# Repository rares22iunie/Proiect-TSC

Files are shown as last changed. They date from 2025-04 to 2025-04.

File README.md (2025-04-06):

# OpenBook eBook Reader
Acest proiect reprezintă un cititor de eBook-uri portabil, cu consum redus de energie, afișaj E-Ink și conectivitate modernă, proiectat în jurul microcontrollerului ESP32-C6-WROOM-1-N8.

# Arhitectură hardware
- Microcontroller – ESP32-C6-WROOM-1-N8
- Procesor RISC-V

- Conectivitate: Wi-Fi 6 și Bluetooth 5

- Suport criptografie hardware

- Flash extern NOR de 64MB (W25Q512JVEIQ), conectat pe magistrală SPI dedicată

Interfețe: SPI, I2C, GPIO

## Sistem de alimentare
- Conector USB-C (PMF0501) – intrare standard 5V

- Protecție ESD pentru liniile USB (USBLC6-2SC6Y)

- Circuit de încărcare Li-Po (MCP73831), max. 500 mA

- Baterie Li-Po 3.7V

- Regulator LDO 3.3V (MCP1700-3302E) pentru alimentarea circuitelor

## Afișaj E-Ink
- Conector compatibil cu ecrane E-Paper de 1.54” (200x200 px)

- Circuit dedicat de generare a tensiunii (tranzistor, inductor, diodă)

- Jumper selector pentru tipul de ecran (SJ1)

- Interfață SPI + pini GPIO pentru control, conectat la ESP32-C6

## Memorie externă
- Card SD (SPI) pentru stocarea fișierelor eBook

- Memorie NOR Flash de 64MB (W25Q512JVEIQ) pentru resurse firmware (fonturi, imagini)

## Senzori și periferice
- BME688 – senzor de temperatură, umiditate, presiune, compuși volatili (I2C)

- DS3231SN – modul RTC de precizie (I2C)

- MAX17048G-T10 – monitorizare baterie (fuel gauge, I2C)

- Butoane pentru reset și boot (GPIO)

- Conector Qwiic / Stemma QT pentru extensii rapide I2C
# Block Diagram


# Design PCB și carcasă
- Placă PCB organizată în blocuri funcționale: alimentare, MCU, afișaj, senzori

- Trasee optimizate și plan de masă comun

- Protecții ESD incluse

- Conectori externi ușor accesibili (USB, butoane, display)

- Randări 3D disponibile

- Carcasă 3D compactă și ergonomică, gata de printare/turnare

# Conexiuni ESP32-C6
| Componenta | Interfata  | Pini ESP32-C6 | Observatii |
|---|---|---|---|
| SD Card | SPI | GPIO10, GPIO11, GPIO12, GPIO13 | Bus SPI pentru card SD |
| NOR Flash | SPI | GPIO6, GPIO7, GPIO8, GPIO9 | Bus SPI separat |
| E-Ink Display  | SPI + GPIO | GPIO18, GPIO19, GPIO20, GPIO21 | Control display si date |
| BME688 | I2C | GPIO1 (SDA), GPIO2 (SCL) | Bus comun I2C |
| DS3231 | I2C | GPIO1 (SDA), GPIO2 (SCL) | Comun cu ceilalti senzori |
| MAX17048 | I2C | GPIO1 (SDA), GPIO2 (SCL) | Comun cu ceilalti senzori |
| Butoane | GPIO | GPIO0 (RST), GPIO3 (BOOT) | Control de sistem |
| Test Pads | GPIO/UART  | GPIO17, GPIO22 | Debug |
| Stemma/Qwiic | I2C | GPIO1 (SDA), GPIO2 (SCL) | Extensii rapide |

# Estimare consum de energie
| Modul | Consum mediu |
|---|---|
| ESP32-C6 activ | ~80-100 mA |
| ESP32-C6 deep sleep | ~10 uA |
| E-Ink refresh | ~25 mA (temporar) |
| SD Card (idle/acces) | ~2 mA / ~50 mA |
| RTC + BME688 standby | ~3-5 uA |
| MAX17048 | ~3 uA |

**Durata estimata cu baterie 500mAh:**

- Utilizare activă: 15–20 ore

- Standby (deep sleep): până la câteva săptămâni

# Bill of Materials

| Cantitate | Componentă | Valoare | Descriere | Carcasă | Reper | Link Cumpărare | Datasheet |
|---|---|---|---|---|---|---|---|
| 1 | ADAFRUIT_LEDCHIP-LED0603 | - | LED | ADAFRUIT_CHIP-LED0603 | CHG_LED | [link](https://www.mouser.com/ProductDetail/Adafruit/CHIP-LED0603) | [datasheet](https://www.mouser.com/datasheet/2/737/CHIP-LED0603-1877199.pdf) |
| 1 | SJ | - | SMD solder JUMPER | SJ | SJ1 | [link](https://www.mouser.com/ProductDetail/TE-Connectivity/1-2176091-2) | [datasheet](https://www.mouser.com/datasheet/2/418/1-2176091-2-1817091.pdf) |
| 1 | ESP32_WROVER_EAGLE-LTSPICE_RR0402  | 0.47Ω | Rezistor | ESP32_WROVER_EAGLE-LTSPICE_R0402| R3 | [link](https://www.mouser.com/ProductDetail/Vishay/CRCW04020047ZRT7) | [datasheet](https://www.mouser.com/datasheet/2/427/crcwce-1764191.pdf) |
| 1 | ESP32_WROVER_EAGLE-LTSPICE_RR0402  | 100KΩ | Rezistor | ESP32_WROVER_EAGLE-LTSPICE_R0402| R1_PWRUSB | [link](https://www.mouser.com/ProductDetail/Vishay/CRCW0402100KFKED) | [datasheet](https://www.mouser.com/datasheet/2/427/crcwce-1764191.pdf) |
| 8 | EAGLE-LTSPICE_CC0402 | 100nF | Condensator | EAGLE-LTSPICE_C0402 | C1, C2, C4_USB, C6, C8, C9, C10, C_DELAY | [link](https://www.mouser.com/ProductDetail/Murata/GRM155R71C104KA88D) | [datasheet](https://www.mouser.com/datasheet/2/281/GRM155R71C104KA88D-1767201.pdf) |
| 1 | RCL_CPOL-EUCT3528 | 100µF | Condensator polarizat | RCL_CT3528 | C3 | [link](https://www.mouser.com/ProductDetail/Panasonic/EEE-FK1V101P) | [datasheet](https://www.mouser.com/datasheet/2/315/EEE-FK1V101P-1526881.pdf) |
| 10 | ESP32_WROVER_EAGLE-LTSPICE_RR0402  | 10KΩ | Rezistor | ESP32_WROVER_EAGLE-LTSPICE_R0402| R1, R1-PINH, R1_PINH1, R2-PINH, R2_PINH1, R4, R_BOOT, R_CHANGE, R_CL1, R_RESET | [link](https://www.mouser.com/ProductDetail/Vishay/CRCW040210K0FKED) | [datasheet](https://www.mouser.com/datasheet/2/427/crcwce-1764191.pdf) |
| 6 | ESP32_WROVER_EAGLE-LTSPICE_RR0402  | 10kΩ | Rezistor | ESP32_WROVER_EAGLE-LTSPICE_R0402| R5, R6, R7, R8, R9, R10 | [link](https://www.mouser.com/ProductDetail/Vishay/CRCW040210K0FKED) | [datasheet](https://www.mouser.com/datasheet/2/427/crcwce-1764191.pdf) |
| 1 | EAGLE-LTSPICE_CC0402 | 10µF | Condensator | EAGLE-LTSPICE_C0402 | C7 | [link](https://www.mouser.com/ProductDetail/Murata/GRM155R61A106ME44D) | [datasheet](https://www.mouser.com/datasheet/2/281/GRM155R61A106ME44D-1767201.pdf) |
| 1 | 112A-TAAR-R03_ATTEND | - | Micro SD Card Socket, Push-Push Type | 112ATAARR03ATTEND | J4 | [link](https://www.mouser.com/ProductDetail/Attend/112A-TAAR-R03) | [datasheet](https://www.mouser.com/datasheet/2/828/112A-TAAR-R03-1222862.pdf) |
| 1 | ESP32_WROVER_EAGLE-LTSPICE_RR0402  | 15Ω | Rezistor | ESP32_WROVER_EAGLE-LTSPICE_R0402| R_CAPACITOR  | [link](https://www.mouser.com/ProductDetail/Vishay/CRCW040215R0FKED) | [datasheet](https://www.mouser.com/datasheet/2/427/crcwce-1764191.pdf) |
| 1 | EAGLE-LTSPICE_CC0402 | 1µF | Condensator | EAGLE-LTSPICE_C0402 | C5 | [link](https://www.mouser.com/ProductDetail/Murata/GRM155R61A105KE15D) | [datasheet](https://www.mouser.com/datasheet/2/281/GRM155R61A105KE15D-1767201.pdf) |
| 10 | EAGLE-LTSPICE_CC0402 | 1µF/50V | Condensator ceramic multi-strat | 0402 | EPD_C1, EPD_C2, EPD_C5, EPD_C6, EPD_C7, EPD_C8, EPD_C9, EPD_C10, EPD_C11, EPD_C12 | [link](https://www.mouser.com/ProductDetail/Murata-Electronics/GRM155R61A105KE15D) | [datasheet](https://www.mouser.com/datasheet/2/281/1/GRM155R61A105KE15_01A-1983730.pdf) |

# Aplicații posibile
- eBook Reader offline

- Afișaj de birou cu date locale (calendar, vreme, informații personale)

- Platformă portabilă pentru aplicații IoT low-power

# Resurse
- Documentație oficială ESP32-C6: https://www.espressif.com/en/products/modules/esp32-c6

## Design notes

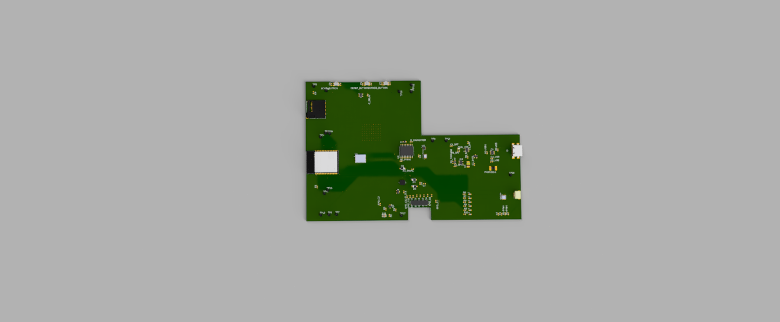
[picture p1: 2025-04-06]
Images/Board render.png

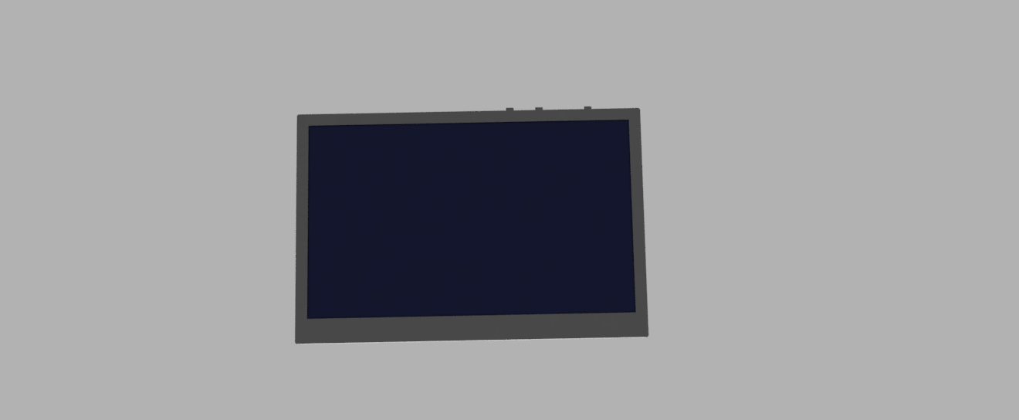
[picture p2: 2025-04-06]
Images/Device front render.PNG

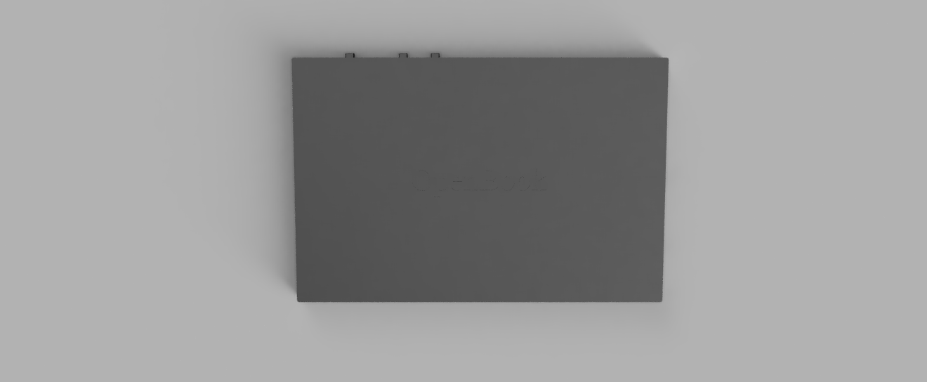
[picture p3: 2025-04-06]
Images/Device rear render.PNG

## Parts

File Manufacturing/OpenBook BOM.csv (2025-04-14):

Qty | Value | Device | Package | Parts | Description | ARROW_PART_NUMBER | ARROW_PRICE-STOCK | AVAILABILITY | CENTROID_NOT_SPECIFIED | CHECK_PRICES | COPYRIGHT | DATASHEET | DESCRIPTION | DIGIKEY_DESCRIPTION | DIGIKEY_PART_NUMBER | HEIGHT | LEAD_FREE | MANUFACTURER_NAME | MANUFACTURER_PART_NUMBER | MF | MFR_NAME | MOUSER_PART_NUMBER | MOUSER_PRICE-STOCK | MOUSER_TESTING_PART_NUMBER | MOUSER_TESTING_PRICE-STOCK | MP | MPN | PACKAGE | POPULARITY | PREFIX | PRICE | PROD_ID | PURCHASE-URL | ROHS | SNAPEDA_LINK | SPICEMODEL | SPICEPREFIX | TEMPERATURE_RANGE_HIGH | TEMPERATURE_RANGE_LOW | TP_SIGNAL_NAME | VALUE
1 |  | ADAFRUIT_LEDCHIP-LED0603 | ADAFRUIT_CHIP-LED0603 | CHG_LED | LED
1 |  | SJ | SJ | SJ1 | SMD solder JUMPER |  |  |  |  |  |  |  |  |  |  |  |  |  |  |  |  |  |  |  |  |  |  |  | 3
1 | 0.1uF/50V | EAGLE-LTSPICE_CC0402 | EAGLE-LTSPICE_C0402 | EPD_C5 | CAPACITOR, European symbol |  |  |  |  |  |  |  |  |  |  |  |  |  |  |  |  |  |  |  |  |  |  |  |  |  |  |  |  |  |  | NONE | C
1 | 0.47 | ESP32_WROVER_EAGLE-LTSPICE_RR0402 | ESP32_WROVER_EAGLE-LTSPICE_R0402 | R3 | RESISTOR, European symbol |  |  |  |  |  |  |  |  |  |  |  |  |  |  |  |  |  |  |  |  |  |  |  |  |  |  |  |  |  |  | NONE | R
1 | 100K | ESP32_WROVER_EAGLE-LTSPICE_RR0402 | ESP32_WROVER_EAGLE-LTSPICE_R0402 | R1_PWRUSB | RESISTOR, European symbol |  |  |  |  |  |  |  |  |  |  |  |  |  |  |  |  |  |  |  |  |  |  |  |  |  |  |  |  |  |  | NONE | R
8 | 100nF | EAGLE-LTSPICE_CC0402 | EAGLE-LTSPICE_C0402 | C1, C2, C4_USB, C6, C8, C9, C10, C_DELAY | CAPACITOR, European symbol |  |  |  |  |  |  |  |  |  |  |  |  |  |  |  |  |  |  |  |  |  |  |  |  |  |  |  |  |  |  | NONE | C
1 | 100uF TANT | RCL_CPOL-EUCT3528 | RCL_CT3528 | C3 | POLARIZED CAPACITOR, European symbol |  |  |  |  |  |  |  |  |  |  |  |  |  |  |  |  |  |  |  |  |  |  |  | 0 |  |  |  |  |  |  |  | C
10 | 10K | ESP32_WROVER_EAGLE-LTSPICE_RR0402 | ESP32_WROVER_EAGLE-LTSPICE_R0402 | R1, R1-PINH, R1_PINH1, R2-PINH, R2_PINH1, R4, R_BOOT, R_CHANGE, R_CL1, R_RESET | RESISTOR, European symbol |  |  |  |  |  |  |  |  |  |  |  |  |  |  |  |  |  |  |  |  |  |  |  |  |  |  |  |  |  |  | NONE | R
6 | 10k | ESP32_WROVER_EAGLE-LTSPICE_RR0402 | ESP32_WROVER_EAGLE-LTSPICE_R0402 | R5, R6, R7, R8, R9, R10 | RESISTOR, European symbol |  |  |  |  |  |  |  |  |  |  |  |  |  |  |  |  |  |  |  |  |  |  |  |  |  |  |  |  |  |  | NONE | R
1 | 10uF | EAGLE-LTSPICE_CC0402 | EAGLE-LTSPICE_C0402 | C7 | CAPACITOR, European symbol |  |  |  |  |  |  |  |  |  |  |  |  |  |  |  |  |  |  |  |  |  |  |  |  |  |  |  |  |  |  | NONE | C
1 | 112A-TAAR-R03_ATTEND | 112A-TAAR-R03_ATTEND | 112ATAARR03ATTEND | J4 | Micro SD Card Socket, Push-Push Type, Top Mount, SMT, H=1.83mm, 10u |  |  |  |  |  |  |  | Micro SD Card Socket | Push-Push Type | Top Mount | SMT | H=1.83mm | 10u |  |  | 1.9mm |  | ATTEND | 112A-TAAR-R03 ATTEND
1 | 15 | ESP32_WROVER_EAGLE-LTSPICE_RR0402 | ESP32_WROVER_EAGLE-LTSPICE_R0402 | R_CAPACITOR | RESISTOR, European symbol |  |  |  |  |  |  |  |  |  |  |  |  |  |  |  |  |  |  |  |  |  |  |  |  |  |  |  |  |  |  | NONE | R
1 | 1uF | EAGLE-LTSPICE_CC0402 | EAGLE-LTSPICE_C0402 | C5 | CAPACITOR, European symbol |  |  |  |  |  |  |  |  |  |  |  |  |  |  |  |  |  |  |  |  |  |  |  |  |  |  |  |  |  |  | NONE | C
9 | 1uF/50V | EAGLE-LTSPICE_CC0402 | EAGLE-LTSPICE_C0402 | EPD_C1, EPD_C2, EPD_C6, EPD_C7, EPD_C8, EPD_C9, EPD_C10, EPD_C11, EPD_C12 | CAPACITOR, European symbol |  |  |  |  |  |  |  |  |  |  |  |  |  |  |  |  |  |  |  |  |  |  |  |  |  |  |  |  |  |  | NONE | C
1 | 2.2 | ESP32_WROVER_EAGLE-LTSPICE_RR0402 | ESP32_WROVER_EAGLE-LTSPICE_R0402 | R2 | RESISTOR, European symbol |  |  |  |  |  |  |  |  |  |  |  |  |  |  |  |  |  |  |  |  |  |  |  |  |  |  |  |  |  |  | NONE | R
1 | 200 | ESP32_WROVER_EAGLE-LTSPICE_RR0402 | ESP32_WROVER_EAGLE-LTSPICE_R0402 | R1_BAT | RESISTOR, European symbol |  |  |  |  |  |  |  |  |  |  |  |  |  |  |  |  |  |  |  |  |  |  |  |  |  |  |  |  |  |  | NONE | R
2 | 20V/4.2A/52mO/1.4W | ESP32_WROVER_SPARKFUN-DISCRETESEMI_MOSFET_PCH-DMG2305UX-7 | ESP32_WROVER_SPARKFUN-DISCRETESEMI_SOT23-3 | Q1, Q2 | P-channel MOSFETs |  |  |  |  |  |  |  |  |  |  |  |  |  |  |  |  |  |  |  |  |  |  |  |  |  |  | TRAN-14388 |  |  |  |  |  |  |  |  | 20V/4.2A/52mO/1.4W
1 | 2K | ESP32_WROVER_EAGLE-LTSPICE_RR0402 | ESP32_WROVER_EAGLE-LTSPICE_R0402 | R2_BAT | RESISTOR, European symbol |  |  |  |  |  |  |  |  |  |  |  |  |  |  |  |  |  |  |  |  |  |  |  |  |  |  |  |  |  |  | NONE | R
4 | 4.7uF | EAGLE-LTSPICE_CC0402 | EAGLE-LTSPICE_C0402 | C1_BAT, C1_BAT2, C2_BAT, C5_USB | CAPACITOR, European symbol |  |  |  |  |  |  |  |  |  |  |  |  |  |  |  |  |  |  |  |  |  |  |  |  |  |  |  |  |  |  | NONE | C
1 | 4.7uF | ESP32_WROVER_EAGLE-LTSPICE_CC0402 | ESP32_WROVER_EAGLE-LTSPICE_C0402 | C1_BAT1 | CAPACITOR, European symbol |  |  |  |  |  |  |  |  |  |  |  |  |  |  |  |  |  |  |  |  |  |  |  |  |  |  |  |  |  |  | NONE | C
1 | 4.7uF/25V | EAGLE-LTSPICE_CC0402 | EAGLE-LTSPICE_C0402 | C4 | CAPACITOR, European symbol |  |  |  |  |  |  |  |  |  |  |  |  |  |  |  |  |  |  |  |  |  |  |  |  |  |  |  |  |  |  | NONE | C
1 | 5K1 | ESP32_WROVER_EAGLE-LTSPICE_RR0402 | ESP32_WROVER_EAGLE-LTSPICE_R0402 | R2-USB1 | RESISTOR, European symbol |  |  |  |  |  |  |  |  |  |  |  |  |  |  |  |  |  |  |  |  |  |  |  |  |  |  |  |  |  |  | NONE | R
1 | 5k1 | ESP32_WROVER_EAGLE-LTSPICE_RR0402 | ESP32_WROVER_EAGLE-LTSPICE_R0402 | R2-USB | RESISTOR, European symbol |  |  |  |  |  |  |  |  |  |  |  |  |  |  |  |  |  |  |  |  |  |  |  |  |  |  |  |  |  |  | NONE | R
1 | 68uH | 744043680IND_4828-WE-TPC_WRE | IND_4828-WE-TPC_WRE | L1 |  |  |  |  |  |  | Copyright (C) 2024 Ultra Librarian. All rights reserved. |  |  |  |  |  |  |  | 744043680 |  | Wurth Electronics
1 | BD5229G-TR | BD5229G-TR | SOT95P280X125-5N | IC1 | Voltage Detector with Adjustable Delay Time: CMOS processes are utilized to develop high precision, low current consumption CMOS reset ICs that allow arbitrary setting of the delay time. The extensive lineup includes both Nch Open Drain and CMOS output types in a wide range of detection voltages (from 2.3V to 6.0V, in 0.1V steps), enabling selection of the ideal solution based on customer requirements. In addition, the entire series is of course both lead-free and RoHS-compliant. |  |  |  |  |  |  |  | Voltage Detector with Adjustable Delay Time: CMOS processes are utilized to develop high precision | low current consumption CMOS reset ICs that allow arbitrary setting of the delay time. The extensive lineup includes both Nch Open Drain and CMOS output types in a wide range of detection voltages (from 2.3V to 6.0V | in 0.1V steps) | enabling selection of the ideal solution based on customer requirements. In addition | the entire series is of course both lead-free and RoHS-compliant. |  |  | 1.25mm |  | ROHM Semiconductor | BD5229G-TR |  |  | 755-BD5229G-TR | https://www.mouser.co.uk/ProductDetail/ROHM-Semiconductor/BD5229G-TR?qs=4kLU8WoGk0vvnhrrYwdszw%3D%3D
1 | BME688 | ESP32_WROVER_BME680_BME680 | ESP32_WROVER_BME680_PSON80P300X300X100-8N | SENSOR2 | Integrated Environmental Unit |  |  | Unavailable |  |  |  |  | Integrated Environmental Unit |  |  |  |  |  |  | Bosch Sensortec |  |  |  |  |  | BME680 |  | LGA-8 Bosch Tools |  |  | None
3 | BUTTON_CUSYOMV1 | BUTTON_CUSYOMV1 | MYBUTTON | BOOT_BUTTON, CHANGE_BUTTON, RESET_BUTTON
1 | CPH3225A | CPH3225A | CAPCP3225X100N | C10_SUPERCAP | Cap 0.011F 3.3V 1210 Flat Check availability |  |  | Not in stock |  | https://www.snapeda.com/parts/CPH3225A/Seiko+Instruments/view-part/?ref=eda |  |  | 11 mF (EDLC) Supercapacitor 3.3 V 1210 (3225 Metric) - - |  |  |  |  |  |  | Seiko Instruments |  |  |  |  |  | CPH3225A |  | 1210 Seiko |  |  | None |  | https://www.snapeda.com/api/url_track_click_mouser/?unipart_id=562593&manufacturer=Seiko Instruments&part_name=CPH3225A&search_term=None |  | https://www.snapeda.com/parts/CPH3225A/Seiko+Instruments/view-part/?ref=snap
1 | DS3231SN# | DS3231SN# | SOIC127P1032X265-16N | U3 | Real Time Clock Serial 16-Pin SOIC W T/R Check availability |  |  | In Stock |  | https://www.snapeda.com/parts/DS3231SN%23/Analog+Devices/view-part/?ref=eda |  |  | Extremely Accurate I²C-Integrated RTC/TCXO/Crystal |  |  |  |  |  |  | Analog Devices |  |  |  |  |  | DS3231SN# |  | SOIC-16 Maxim |  |  | None |  | https://www.snapeda.com/api/url_track_click_mouser/?unipart_id=99048&manufacturer=Analog Devices&part_name=DS3231SN#&search_term=None |  | https://www.snapeda.com/parts/DS3231SN%23/Analog+Devices/view-part/?ref=snap
1 | ESP32-C6-WROOM-1-N8 | ESP32-C6-WROOM-1-N8 | XCVR_ESP32-C6-WROOM-1-N8 | U2 | Check availability |  |  | In Stock |  | https://www.snapeda.com/parts/ESP32-C6-WROOM-1-N8/Espressif+Systems/view-part/?ref=eda |  |  | Multiprotocol Modules ESP32-C6 module | Wi-Fi 6 in 2.4 GHz band | Bluetooth 5 | Zigbee 3.0 and Thread. ESP34-WROOM Compatible - ENGINEERING SAMPLE |  |  |  |  |  |  | Espressif Systems |  |  |  |  |  | ESP32-C6-WROOM-1-N8 |  | None |  |  | None |  |  |  | https://www.snapeda.com/parts/ESP32-C6-WROOM-1-N8/Espressif+Systems/view-part/?ref=snap
1 | ESP32C6_VARISTORCN1812 | ESP32C6_VARISTORCN1812 | ESP32C6_VARISTOR_CT/CN1812 | PFMF.050.1 | VARISTOR |  |  |  |  |  |  |  |  |  |  |  |  |  |  |  |  |  |  |  |  |  |  |  | 0
2 | ESP32_WROVER_AVX---SD0805S020S1R0_AVX_SD0805S020S1R0_0_0AVX_SD0805S020S1R0_0_0 | ESP32_WROVER_AVX---SD0805S020S1R0_AVX_SD0805S020S1R0_0_0AVX_SD0805S020S1R0_0_0 | ESP32_WROVER_AVX---SD0805S020S1R0_AVX_SD0805S020S1R0_0 | D2, D7 | Schottky Barrier Rectifier Diode |  |  |  | No |  |  | http://datasheets.avx.com/schottky.pdf |  | DIODE SCHOTTKY 20V 1A 0805 | 478-7800-1-ND |  | yes |  |  | AVX |  | 581-SD0805S020S1R0 |  |  |  |  |  | 0805 (2012 metric) |  | D |  |  |  | yes |  |  |  | +125°C | -55°C
1 | ESP32_WROVER_SPARKFUN-IC-POWER_MCP73831 | ESP32_WROVER_SPARKFUN-IC-POWER_MCP73831 | ESP32_WROVER_SPARKFUN-IC-POWER_SOT23-5 | U5 | MCP73831T Li-Ion, Li-Pol Controller |  |  |  |  |  |  |  |  |  |  |  |  |  |  |  |  |  |  |  |  |  |  |  |  |  |  | IC-09995
1 | FH34SRJ-24S-0.5SH_99_ | FH34SRJ-24S-0.5SH_99_ | FH34SRJ24S05SH99 | J1 | (0.50mm) Surface Mount, Right Angle |  |  |  |  |  |  |  | 24 Position FFC | FPC Connector Contacts | (0.50mm) Surface Mount | Right Angle |  |  | 1.1mm |  | Hirose | FH34SRJ-24S-0.5SH(99) |  |  | 798-FH34SRJ24S05SH99 | https://www.mouser.co.uk/ProductDetail/Hirose-Connector/FH34SRJ-24S-0.5SH99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
1 | MAX17048G+T10 | MAX17048G+T10 | SON50P200X200X80-9N | U4 | Check availability |  |  | In Stock |  | https://www.snapeda.com/parts/MAX17048G+T10/Analog+Devices/view-part/?ref=eda |  |  | 3µA 1-Cell/2-Cell Fuel Gauge with ModelGauge |  |  |  |  |  |  | Analog Devices |  |  |  |  |  | MAX17048G+T10 |  | TDFN-8 Maxim |  |  | None |  | https://www.snapeda.com/api/url_track_click_mouser/?unipart_id=329239&manufacturer=Analog Devices&part_name=MAX17048G+T10&search_term=None |  | https://www.snapeda.com/parts/MAX17048G+T10/Analog+Devices/view-part/?ref=snap
3 | MBR0530 | MBR0530 | SOD3716X135N | D3, D4, D5 | ON SEMICONDUCTOR - MBR0530 - DIODE, SCHOTTKY, 0.5A, 30V, SOD-123 |  |  | In Stock |  | https://www.snapeda.com/parts/MBR0530/Onsemi/view-part/?ref=eda |  |  | Diode Schottky 30 V 500mA Surface Mount SOD-123 |  |  |  |  |  |  | ON Semiconductor |  |  |  |  |  | MBR0530 |  | SOD-123-2 ON Semiconductor |  |  | None |  | https://www.snapeda.com/api/url_track_click_mouser/?unipart_id=179458&manufacturer=ON Semiconductor&part_name=MBR0530&search_term=None |  | https://www.snapeda.com/parts/MBR0530/Onsemi/view-part/?ref=snap
6 | PGB1010603MR | PGB1010603MR | DIOC1608X36N | D6, D8, D9, D10, D11, D12 | Check availability |  |  | In Stock |  | https://www.snapeda.com/parts/PGB1010603MR/Littelfuse/view-part/?ref=eda |  |  | 150V (Typ) Clamp - Ipp Tvs Diode Surface Mount 0603 (1608 Metric) |  |  |  |  |  |  | Littelfuse Inc. |  |  |  |  |  | PGB1010603MR |  | 0603 Littelfuse Inc. |  |  | None |  | https://www.snapeda.com/api/url_track_click_mouser/?unipart_id=5659453&manufacturer=Littelfuse Inc.&part_name=PGB1010603MR&search_term=None |  | https://www.snapeda.com/parts/PGB1010603MR/Littelfuse/view-part/?ref=snap
1 | QWIIC_RIGHT_ANGLE | QWIIC_CONNECTORJS-1MM | JST04_1MM_RA | J3 | SparkFun I2C Standard Qwiic Connector |  |  |  |  |  |  |  |  |  |  |  |  |  |  |  |  |  |  |  |  |  |  |  |  |  |  | CONN-13694 |  |  |  |  |  |  |  |  | QWIIC_RIGHT_ANGLE
1 | SAMACSYS_PARTS_USB4110-GF-A | SAMACSYS_PARTS_USB4110-GF-A | SAMACSYS_PARTS_USB4110GFA | J2 | CONN USB 2.0 TYPE-C R/A SMT |  |  |  |  |  |  |  | CONN USB 2.0 TYPE-C R/A SMT |  |  | 3.26mm |  | GCT (GLOBAL CONNECTOR TECHNOLOGY) | USB4110-GF-A |  |  | 640-USB4110-GF-A | https://www.mouser.co.uk/ProductDetail/GCT/USB4110-GF-A?qs=KUoIvG%2F9IlYiZvIXQjyJeA%3D%3D
1 | SI1308EDL-T1-GE3 | SI1308EDL-T1-GE3 | SOT65P210X110-3N | Q3 | MOSFET N-Ch 30V 1.5A TrenchFET SC70 Vishay Si1308EDL-T1-GE3 N-channel MOSFET Transistor, 1.5 A, 30 V, 3-Pin SC-70 |  |  | In Stock |  | https://www.snapeda.com/parts/SI1308EDL-T1-GE3/Vishay+Siliconix/view-part/?ref=eda |  |  | Si1308EDL-T1-GE3 N-channel MOSFET Transistor | 1.5 A | 30 V | 3-Pin SC-70 | Siliconix / Vishay SI1308EDL-T1-GE3 |  |  |  |  |  |  | Vishay Siliconix |  |  |  |  |  | SI1308EDL-T1-GE3 |  | SOT-323 Vishay Semiconductor |  |  | None |  | https://www.snapeda.com/api/url_track_click_mouser/?unipart_id=274603&manufacturer=Vishay Siliconix&part_name=SI1308EDL-T1-GE3&search_term=None |  | https://www.snapeda.com/parts/SI1308EDL-T1-GE3/Vishay+Siliconix/view-part/?ref=snap
17 | TPTP20R | TPTP20R | TP20R | TP1, TP2, TP3, TP4, TP5, TP6, TP7, TP8, TP9, TP10, TP11, TP12, TP13, TP14, TP15, TP16, TP17 | Test pad |  |  |  |  |  |  |  |  |  |  |  |  |  |  |  |  |  |  |  |  |  |  |  | 2
1 | USBLC6-2SC6Y | USBLC6-2SC6Y | SOT95P280X145-6N | D1 | Low Cap. ESD Protection Auto SOT-23-6 STMicroelectronics USBLC6-2SC6Y, Dual Uni-Directional TVS Diode Array, 6-Pin SOT-23 |  |  | In Stock |  | https://www.snapeda.com/parts/USBLC6-2SC6Y/STMicroelectronics/view-part/?ref=eda |  |  | 17V Clamp 5A (8/20µs) Ipp Tvs Diode Surface Mount SOT-23-6 |  |  |  |  |  |  | STMicroelectronics |  |  |  |  |  | USBLC6-2SC6Y |  | SOT-23-6 STMicroelectronics |  |  | None |  |  |  | https://www.snapeda.com/parts/USBLC6-2SC6Y/STMicroelectronics/view-part/?ref=snap
1 | W25Q512JVEIQ | W25Q512JVEIQ | SON127P600X800X80-9N | U1 | Check availability |  |  | In Stock |  | https://www.snapeda.com/parts/W25Q512JVEIQ/Winbond+Electronics/view-part/?ref=eda |  |  | FLASH - NOR Memory IC 512Mb (64M x 8) SPI - Quad I/O 133 MHz 8-WSON (8x6) |  |  |  |  |  |  | Winbond Electronics |  |  |  |  |  | W25Q512JVEIQ |  | Package |  |  | None |  |  |  | https://www.snapeda.com/parts/W25Q512JVEIQ/Winbond+Electronics/view-part/?ref=snap
1 | XC6220A331MR-G | XC6220A331MR-G | SOT95P280X120-5N | IC4 | LDO Voltage Regulators |  |  |  |  |  |  |  | LDO Voltage Regulators |  |  | 1.2mm |  | Torex | XC6220A331MR-G |  |  | 865-XC6220A331MR-G | https://www.mouser.co.uk/ProductDetail/Torex-Semiconductor/XC6220A331MR-G?qs=AsjdqWjXhJ8ZSWznL1J0gg%3D%3D

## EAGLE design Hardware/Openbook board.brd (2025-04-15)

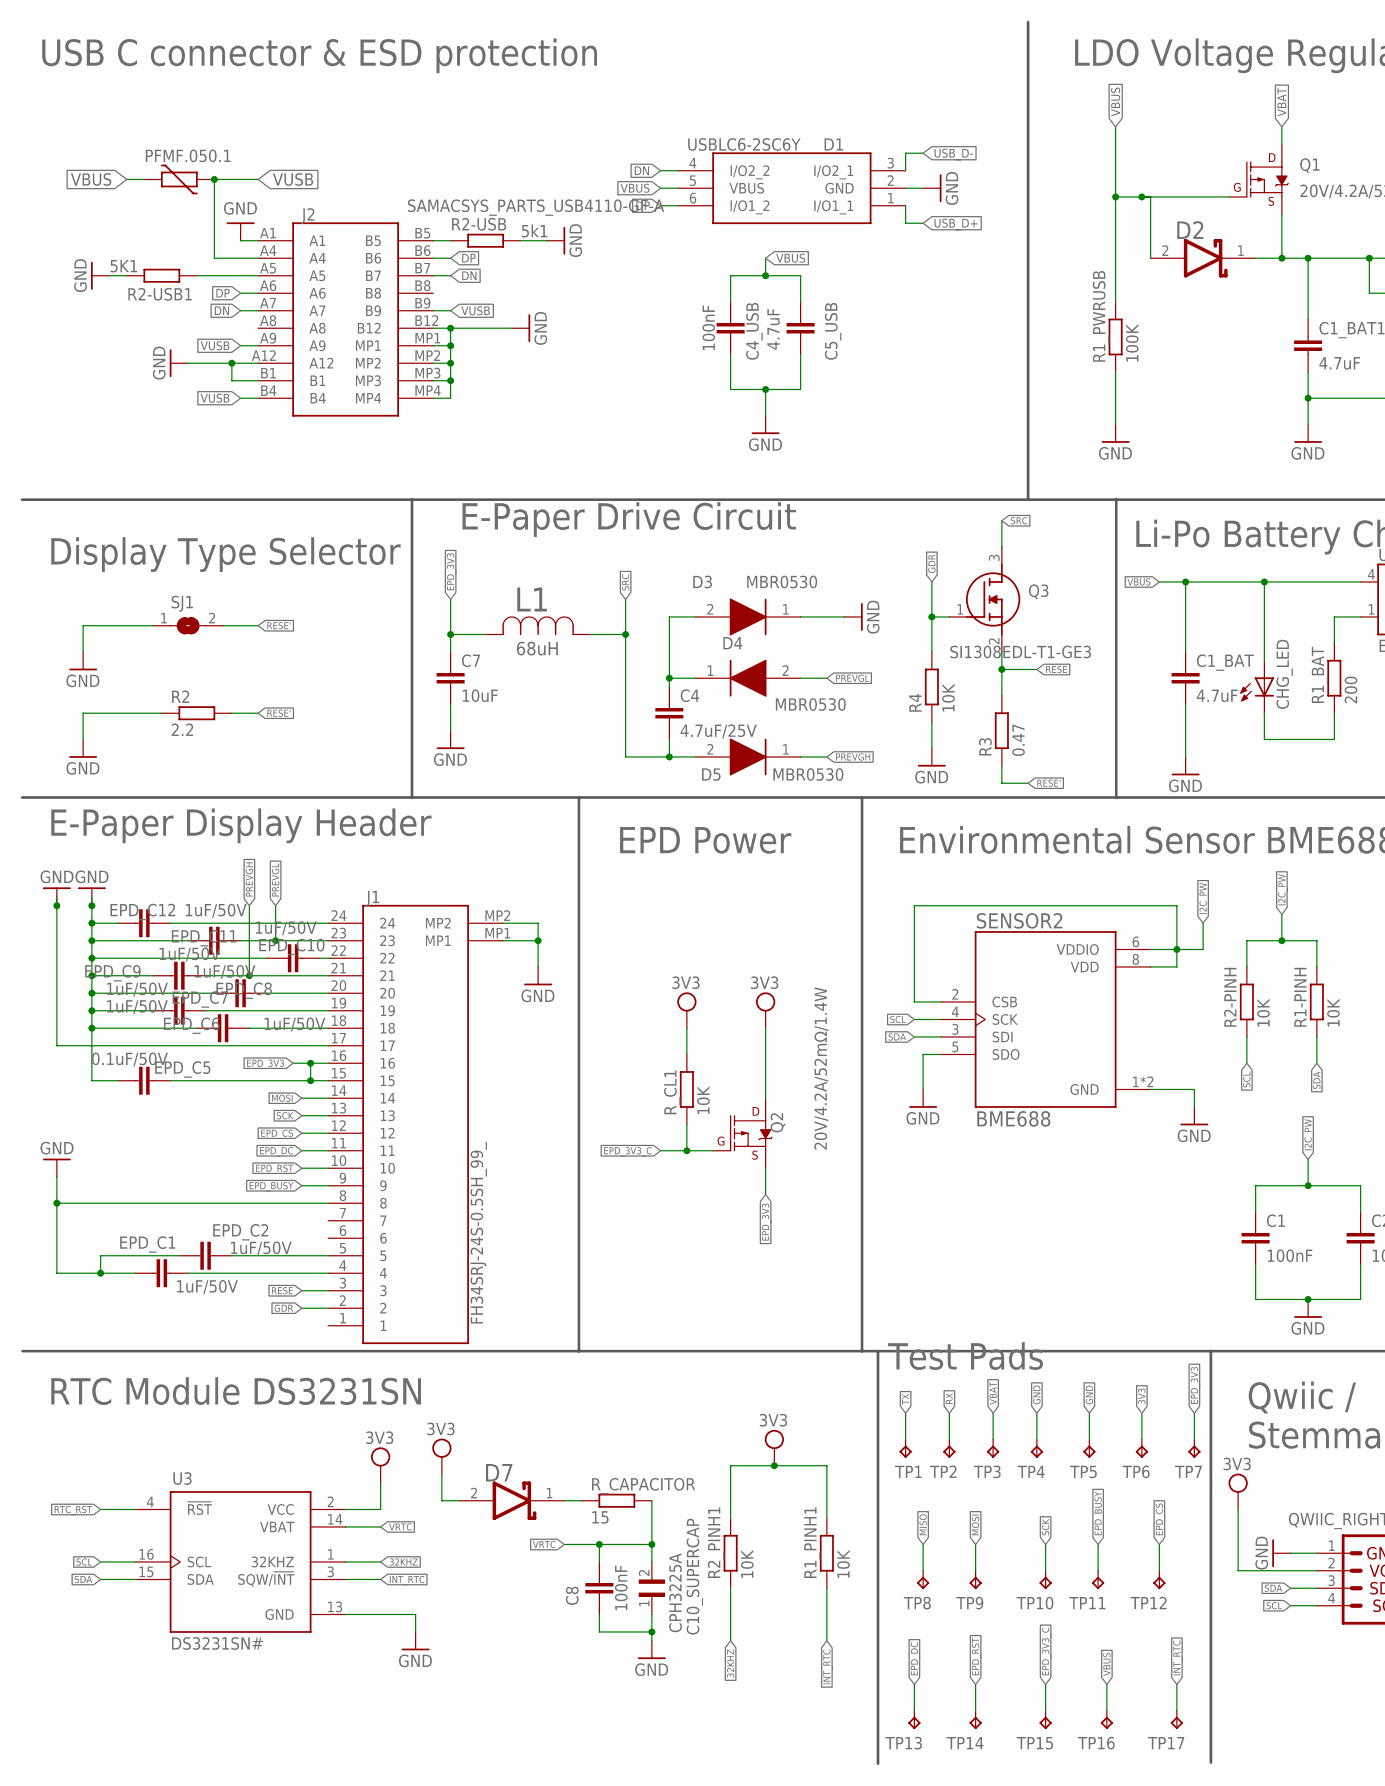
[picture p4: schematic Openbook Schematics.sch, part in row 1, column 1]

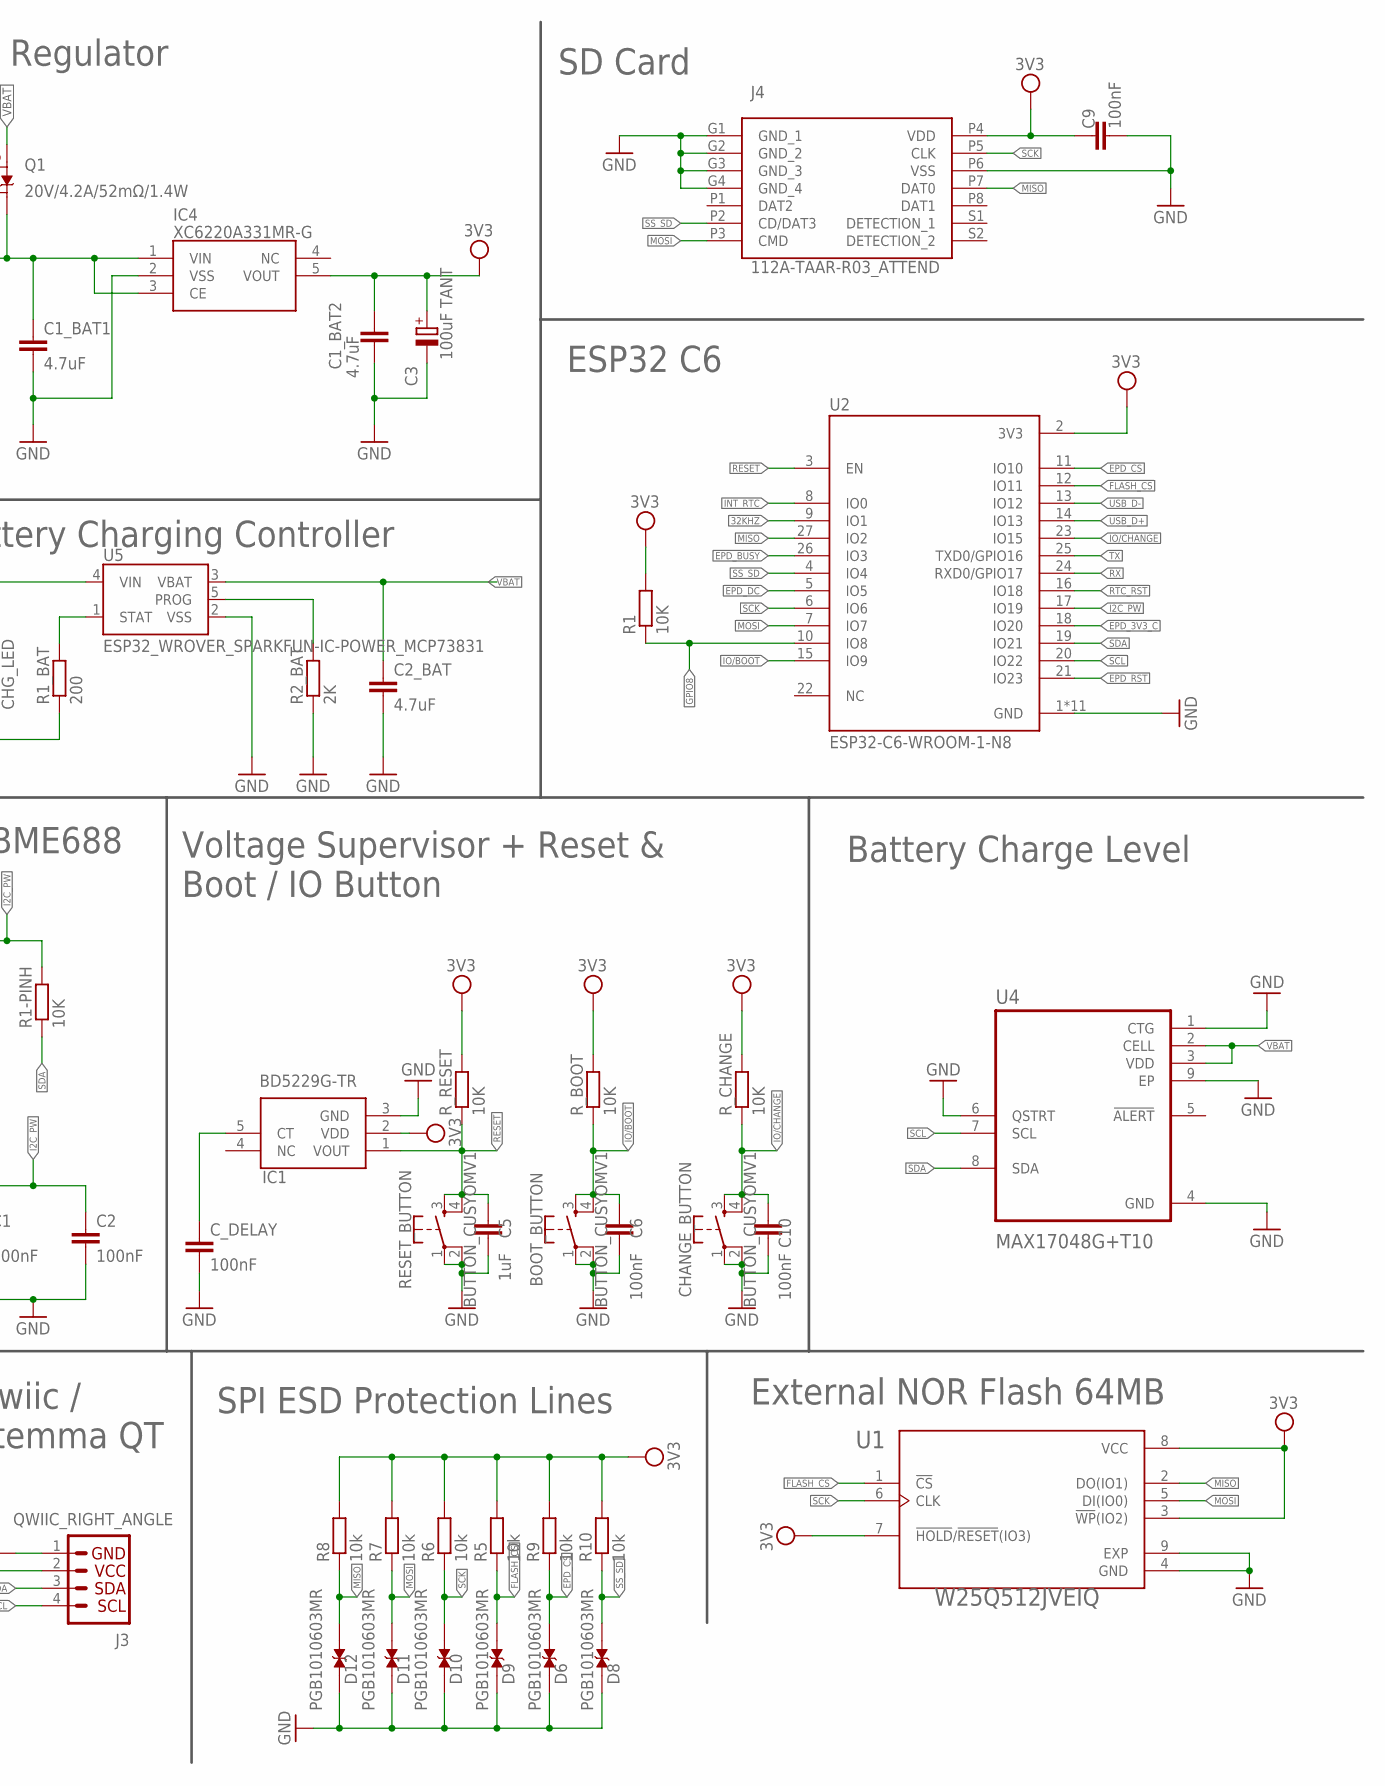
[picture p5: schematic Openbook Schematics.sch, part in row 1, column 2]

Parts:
BOOT_BUTTON: BUTTON_CUSYOMV1; MYBUTTON
C1, C2, C4_USB, C6, C8, C9, C10: 100nF; EAGLE-LTSPICE_C0402
C1_BAT, C1_BAT2, C2_BAT, C5_USB: 4.7uF; EAGLE-LTSPICE_C0402
C1_BAT1: 4.7uF; ESP32_WROVER_EAGLE-LTSPICE_C0402
C3: 100uF TANT; RCL_CT3528
C4: 4.7uF/25V; EAGLE-LTSPICE_C0402
C5: 1uF; EAGLE-LTSPICE_C0402
C7: 10uF; EAGLE-LTSPICE_C0402
C10_SUPERCAP: CPH3225A; CAPCP3225X100N
CHANGE_BUTTON: BUTTON_CUSYOMV1; MYBUTTON
CHG_LED: ADAFRUIT_LEDCHIP-LED0603; ADAFRUIT_CHIP-LED0603
C_DELAY: 100nF; EAGLE-LTSPICE_C0402
D1: USBLC6-2SC6Y; SOT95P280X145-6N
D2, D7: ESP32_WROVER_AVX---SD0805S020S1R0_AVX_SD0805S020S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; ESP32_WROVER_AVX---SD0805S020S1R0_AVX_SD0805S020S1R0_0
D3, D4, D5: MBR0530; SOD3716X135N
D6, D8, D9, D10, D11, D12: PGB1010603MR; DIOC1608X36N
EPD_C1, EPD_C2, EPD_C6, EPD_C7, EPD_C8, EPD_C9, EPD_C10, EPD_C11, EPD_C12: 1uF/50V; EAGLE-LTSPICE_C0402
EPD_C5: 0.1uF/50V; EAGLE-LTSPICE_C0402
IC1: BD5229G-TR; SOT95P280X125-5N
IC4: XC6220A331MR-G; SOT95P280X120-5N
J1: FH34SRJ-24S-0.5SH_99_; FH34SRJ24S05SH99
J2: SAMACSYS_PARTS_USB4110-GF-A; SAMACSYS_PARTS_USB4110GFA
J3: QWIIC_RIGHT_ANGLE; JST04_1MM_RA
J4: 112A-TAAR-R03_ATTEND; 112ATAARR03ATTEND
L1: 68uH; IND_4828-WE-TPC_WRE
PFMF.050.1: ESP32C6_VARISTORCN1812; ESP32C6_VARISTOR_CT/CN1812
Q1, Q2: 20V/4.2A/52mΩ/1.4W; ESP32_WROVER_SPARKFUN-DISCRETESEMI_SOT23-3
Q3: SI1308EDL-T1-GE3; SOT65P210X110-3N
R1, R1-PINH, R1_PINH1, R2-PINH, R2_PINH1, R4: 10K; ESP32_WROVER_EAGLE-LTSPICE_R0402
R1_BAT: 200; ESP32_WROVER_EAGLE-LTSPICE_R0402
R1_PWRUSB: 100K; ESP32_WROVER_EAGLE-LTSPICE_R0402
R2: 2.2; ESP32_WROVER_EAGLE-LTSPICE_R0402
R2-USB: 5k1; ESP32_WROVER_EAGLE-LTSPICE_R0402
R2-USB1: 5K1; ESP32_WROVER_EAGLE-LTSPICE_R0402
R2_BAT: 2K; ESP32_WROVER_EAGLE-LTSPICE_R0402
R3: 0.47; ESP32_WROVER_EAGLE-LTSPICE_R0402
R5, R6, R7, R8, R9, R10: 10k; ESP32_WROVER_EAGLE-LTSPICE_R0402
RESET_BUTTON: BUTTON_CUSYOMV1; MYBUTTON
R_BOOT: 10K; ESP32_WROVER_EAGLE-LTSPICE_R0402
R_CAPACITOR: 15; ESP32_WROVER_EAGLE-LTSPICE_R0402
R_CHANGE: 10K; ESP32_WROVER_EAGLE-LTSPICE_R0402
R_CL1: 10K; ESP32_WROVER_EAGLE-LTSPICE_R0402
R_RESET: 10K; ESP32_WROVER_EAGLE-LTSPICE_R0402
SENSOR2: BME688; ESP32_WROVER_BME680_PSON80P300X300X100-8N
SJ1: SJ
TP1, TP2, TP3, TP4, TP5, TP6, TP7, TP8, TP9, TP10, TP11, TP12, TP13, TP14, TP15, TP16, TP17: TPTP20R; TP20R
U1: W25Q512JVEIQ; SON127P600X800X80-9N
U2: ESP32-C6-WROOM-1-N8; XCVR_ESP32-C6-WROOM-1-N8
U3: DS3231SN#; SOIC127P1032X265-16N
U4: MAX17048G+T10; SON50P200X200X80-9N
U5: ESP32_WROVER_SPARKFUN-IC-POWER_MCP73831; ESP32_WROVER_SPARKFUN-IC-POWER_SOT23-5

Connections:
3V3: C1_BAT2.1, C3.+, C9.2, D7.2 (ANODE), IC1.2 (VDD), IC4.5 (VOUT), J3.2, J4.P4 (VDD), Q2.3 (D), R1.2, R1_PINH1.2, R2_PINH1.2, R5.2, R6.2, R7.2, R8.2, R9.2, R10.2, R_BOOT.2, R_CHANGE.2, R_CL1.2, R_RESET.2, TP6.TP, U1.3 (!WP!(IO2)), U1.7 (!HOLD!/!RESET!(IO3)), U1.8 (VCC), U2.2 (3V3), U3.2 (VCC)
32KHZ: R2_PINH1.1, U2.9 (IO1), U3.1 (32KHZ)
DN: D1.4 (I/O2_2), J2.A7, J2.B7
DP: D1.6 (I/O1_2), J2.A6, J2.B6
EPD_3V3: C7.1, EPD_C5.2, J1.15, J1.16, L1.2, Q2.2 (S), TP7.TP
EPD_3V3_C: Q2.1 (G), R_CL1.1, TP15.TP, U2.18 (IO20)
EPD_BUSY: J1.9, TP11.TP, U2.26 (IO3)
EPD_CS: D6.2, J1.12, R9.1, TP12.TP, U2.11 (IO10)
EPD_DC: J1.11, TP13.TP, U2.5 (IO5)
EPD_RST: J1.10, TP14.TP, U2.21 (IO23)
FLASH_CS: D9.2, R5.1, U1.1 (!CS), U2.12 (IO11)
GDR: J1.2, Q3.1 (G), R4.2
GND: BOOT_BUTTON.1, BOOT_BUTTON.2, C1.2, C1_BAT.2, C1_BAT1.2, C1_BAT2.2, C2.2, C2_BAT.2, C3.-, C4_USB.2, C5.2, C5_USB.2, C6.2, C7.2, C8.2, C9.1, C10.2, C10_SUPERCAP.1, CHANGE_BUTTON.1, CHANGE_BUTTON.2, C_DELAY.2, D1.2 (GND), D3.1 (K), D6.1, D8.1, D9.1, D10.1, D11.1, D12.1, EPD_C1.1, EPD_C2.1, EPD_C5.1, EPD_C6.1, EPD_C7.1, EPD_C8.1, EPD_C9.1, EPD_C10.1, EPD_C11.1, EPD_C12.1, IC1.3 (GND), IC4.2 (VSS), J1.8, J1.17, J1.MP1, J1.MP2, J2.A1, J2.A12, J2.B1, J2.B12, J2.MP1, J2.MP2, J2.MP3, J2.MP4, J3.1, J4.G1 (GND_1), J4.G2 (GND_2), J4.G3 (GND_3), J4.G4 (GND_4), J4.P6 (VSS), R1_PWRUSB.1, R2.1, R2-USB.2, R2-USB1.1, R2_BAT.1, R4.1, RESET_BUTTON.1, RESET_BUTTON.2, SENSOR2.1 (GND), SENSOR2.5 (SDO), SENSOR2.7 (GND), SJ1.1, TP4.TP, TP5.TP, U1.4 (GND), U1.9 (EXP), U2.1 (GND), U2.28 (GND), U2.29_1 (GND), U2.29_2 (GND), U2.29_3 (GND), U2.29_4 (GND), U2.29_5 (GND), U2.29_6 (GND), U2.29_7 (GND), U2.29_8 (GND), U2.29_9 (GND), U3.13 (GND), U4.1 (CTG), U4.4 (GND), U4.6 (QSTRT), U4.9 (EP), U5.2 (VSS)
GPIO8: R1.1, U2.10 (IO8)
I2C_PW: C1.1, C2.1, R1-PINH.2, R2-PINH.2, SENSOR2.2 (CSB), SENSOR2.6 (VDDIO), SENSOR2.8 (VDD), U2.17 (IO19)
INT_RTC: R1_PINH1.1, TP17.TP, U2.8 (IO0), U3.3 (SQW/!INT)
IO/BOOT: BOOT_BUTTON.3, BOOT_BUTTON.4, C6.1, R_BOOT.1, U2.15 (IO9)
IO/CHANGE: C10.1, CHANGE_BUTTON.3, CHANGE_BUTTON.4, R_CHANGE.1, U2.23 (IO15)
MISO: D12.2, J4.P7 (DAT0), R8.1, TP8.TP, U1.2 (DO(IO1)), U2.27 (IO2)
MOSI: D11.2, J1.14, J4.P3 (CMD), R7.1, TP9.TP, U1.5 (DI(IO0)), U2.7 (IO7)
unnamed: J2.A5, R2-USB1.2
unnamed: J2.B5, R2-USB.1
unnamed: C_DELAY.1, IC1.5 (CT)
unnamed: R1_BAT.2, U5.1 (STAT)
unnamed: C1_BAT1.1, D2.1 (CATHODE), IC4.1 (VIN), IC4.3 (CE), Q1.2 (S)
unnamed: C4.1, D3.2 (A), D4.1 (K)
unnamed: CHG_LED.C, R1_BAT.1
unnamed: R2_BAT.2, U5.5 (PROG)
unnamed: EPD_C12.2, J1.24
unnamed: EPD_C10.2, J1.22
unnamed: EPD_C8.2, J1.20
unnamed: EPD_C7.2, J1.19
unnamed: EPD_C6.2, J1.18
unnamed: EPD_C2.2, J1.5
unnamed: EPD_C1.2, J1.4
unnamed: D7.1 (CATHODE), R_CAPACITOR.1
PREVGH: D5.1 (K), EPD_C9.2, J1.21
PREVGL: D4.2 (A), EPD_C11.2, J1.23
RESE: J1.3, Q3.2 (S), R3.2
RESE': R2.2, R3.1, SJ1.2
RESET: C5.1, IC1.1 (VOUT), RESET_BUTTON.3, RESET_BUTTON.4, R_RESET.1, U2.3 (EN)
RTC_RST: U2.16 (IO18), U3.4 (!RST)
RX: TP2.TP, U2.24 (RXD0/GPIO17)
SCK: D10.2, J1.13, J4.P5 (CLK), R6.1, TP10.TP, U1.6 (CLK), U2.6 (IO6)
SCL: J3.4, R2-PINH.1, SENSOR2.4 (SCK), U2.20 (IO22), U3.16 (SCL), U4.7 (SCL)
SDA: J3.3, R1-PINH.1, SENSOR2.3 (SDI), U2.19 (IO21), U3.15 (SDA), U4.8 (SDA)
SRC: C4.2, D5.2 (A), L1.1, Q3.3 (D)
SS_SD: D8.2, J4.P2 (CD/DAT3), R10.1, U2.4 (IO4)
TX: TP1.TP, U2.25 (TXD0/GPIO16)
USB_D+: D1.1 (I/O1_1), U2.14 (IO13)
USB_D-: D1.3 (I/O2_1), U2.13 (IO12)
VBAT: C2_BAT.1, Q1.3 (D), TP3.TP, U4.2 (CELL), U4.3 (VDD), U5.3 (VBAT)
VBUS: C1_BAT.1, C4_USB.1, C5_USB.1, CHG_LED.A, D1.5 (VBUS), D2.2 (ANODE), PFMF.050.1.2, Q1.1 (G), R1_PWRUSB.2, TP16.TP, U5.4 (VIN)
VRTC: C8.1, C10_SUPERCAP.2, R_CAPACITOR.2, U3.14 (VBAT)
VUSB: J2.A4, J2.A9, J2.B4, J2.B9, PFMF.050.1.1

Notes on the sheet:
USB C connector & ESD protection
LDO Voltage Regulator
SD Card
ESP32 C6
Display Type Selector
E-Paper Drive Circuit
Li-Po Battery Charging Controller
E-Paper Display Header
EPD Power
Environmental Sensor BME688
Voltage Supervisor + Reset & Boot / IO Button
Battery Charge Level
External NOR Flash 64MB
SPI ESD Protection Lines
Qwiic / Stemma QT
Test Pads
RTC Module DS3231SN

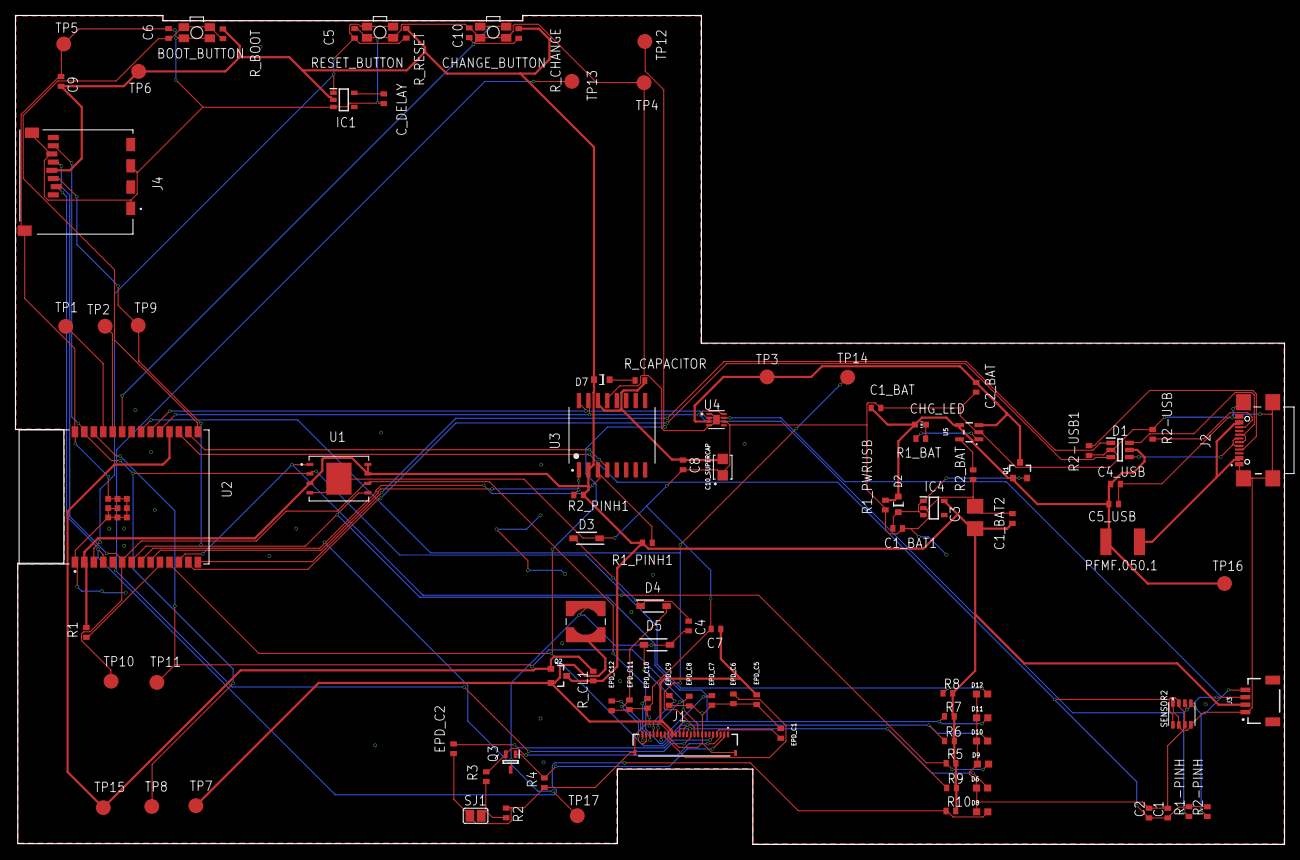
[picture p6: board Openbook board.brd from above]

Board: 2 copper layers, 170.4 x 111.3 mm, 103 parts (0 on the bottom side), 55 nets.

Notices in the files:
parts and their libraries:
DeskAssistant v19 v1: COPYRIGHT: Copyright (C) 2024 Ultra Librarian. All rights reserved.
